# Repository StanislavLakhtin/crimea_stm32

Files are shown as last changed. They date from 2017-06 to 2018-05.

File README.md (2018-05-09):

# crimea_opendac
16 bit usb headphone amplifier on PCM1794A+PGA4311+OPA4134 managed by stm32f103

## Note

It completely doesn't work now.

## CLion Build Env

-DCMAKE_TOOLCHAIN_FILE=libopencm3.cmake

## About

This is complicated "hello world" project for standalone usb sound card and headphone amplifier based on Texas Instruments PCM2707 and STM Cortex-M3 STMF1.

Создаю этот проект для удовольствия. Если исходные коды проекта, схемы или другие материалы проекта будут полезны, буду очень рад.

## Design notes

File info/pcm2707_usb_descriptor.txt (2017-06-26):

as an example

sl@SilverStone:~$ lsusb -D /dev/bus/usb/003/018

Device: ID 08bb:2704 Texas Instruments Audio Codec
Couldn't open device, some information will be missing
Device Descriptor:
  bLength                18
  bDescriptorType         1
  bcdUSB               1.10
  bDeviceClass            0 (Defined at Interface level)
  bDeviceSubClass         0
  bDeviceProtocol         0
  bMaxPacketSize0         8
  idVendor           0x08bb Texas Instruments
  idProduct          0x2704 Audio Codec
  bcdDevice            1.00
  iManufacturer           1
  iProduct                2
  iSerial                 0
  bNumConfigurations      1

  Configuration Descriptor:
    bLength                 9
    bDescriptorType         2
    wTotalLength          190
    bNumInterfaces          3
    bConfigurationValue     1
    iConfiguration          0
    bmAttributes         0x80
      (Bus Powered)
    MaxPower               20mA

    Interface Descriptor:
      bLength                 9
      bDescriptorType         4
      bInterfaceNumber        0
      bAlternateSetting       0
      bNumEndpoints           0
      bInterfaceClass         1 Audio
      bInterfaceSubClass      1 Control Device
      bInterfaceProtocol      0
      iInterface              0

      AudioControl Interface Descriptor:
        bLength                 9
        bDescriptorType        36
        bDescriptorSubtype      1 (HEADER)
        bcdADC               1.00
        wTotalLength           40
        bInCollection           1
        baInterfaceNr( 0)       1

      AudioControl Interface Descriptor:
        bLength                12
        bDescriptorType        36
        bDescriptorSubtype      2 (INPUT_TERMINAL)
        bTerminalID             1
        wTerminalType      0x0101 USB Streaming
        bAssocTerminal          0
        bNrChannels             2
        wChannelConfig     0x0003
          Left Front (L)
          Right Front (R)
        iChannelNames           0
        iTerminal               0

      AudioControl Interface Descriptor:
        bLength                 9
        bDescriptorType        36
        bDescriptorSubtype      3 (OUTPUT_TERMINAL)
        bTerminalID             2
        wTerminalType      0x0301 Speaker
        bAssocTerminal          0
        bSourceID               3
        iTerminal               0

      AudioControl Interface Descriptor:
        bLength                10
        bDescriptorType        36
        bDescriptorSubtype      6 (FEATURE_UNIT)
        bUnitID                 3
        bSourceID               1
        bControlSize            1
        bmaControls( 0)      0x01
          Mute Control
        bmaControls( 1)      0x02
          Volume Control
        bmaControls( 2)      0x02
          Volume Control
        iFeature                0

    Interface Descriptor:
      bLength                 9
      bDescriptorType         4
      bInterfaceNumber        1
      bAlternateSetting       0
      bNumEndpoints           0
      bInterfaceClass         1 Audio
      bInterfaceSubClass      2 Streaming
      bInterfaceProtocol      0
      iInterface              0

    Interface Descriptor:
      bLength                 9
      bDescriptorType         4
      bInterfaceNumber        1
      bAlternateSetting       1
      bNumEndpoints           1
      bInterfaceClass         1 Audio
      bInterfaceSubClass      2 Streaming
      bInterfaceProtocol      0
      iInterface              0

      AudioStreaming Interface Descriptor:
        bLength                 7
        bDescriptorType        36
        bDescriptorSubtype      1 (AS_GENERAL)
        bTerminalLink           1
        bDelay                  0 frames
        wFormatTag              1 PCM

      AudioStreaming Interface Descriptor:
        bLength                17
        bDescriptorType        36
        bDescriptorSubtype      2 (FORMAT_TYPE)
        bFormatType             1 (FORMAT_TYPE_I)
        bNrChannels             2
        bSubframeSize           2
        bBitResolution         16
        bSamFreqType            3 Discrete
        tSamFreq[ 0]        32000
        tSamFreq[ 1]        44100
        tSamFreq[ 2]        48000

      Endpoint Descriptor:
        bLength                 9
        bDescriptorType         5
        bEndpointAddress     0x02  EP 2 OUT
        bmAttributes            9
          Transfer Type            Isochronous
          Synch Type               Adaptive
          Usage Type               Data
        wMaxPacketSize     0x00c0  1x 192 bytes
        bInterval               1
        bRefresh                0
        bSynchAddress           0
        AudioControl Endpoint Descriptor:
          bLength                 7
          bDescriptorType        37
          bDescriptorSubtype      1 (EP_GENERAL)
          bmAttributes         0x00
          bLockDelayUnits         2 Decoded PCM samples
          wLockDelay            512 Decoded PCM samples
    Interface Descriptor:
      bLength                 9
      bDescriptorType         4
      bInterfaceNumber        1
      bAlternateSetting       2
      bNumEndpoints           1
      bInterfaceClass         1 Audio
      bInterfaceSubClass      2 Streaming
      bInterfaceProtocol      0
      iInterface              0
      AudioStreaming Interface Descriptor:
        bLength                 7
        bDescriptorType        36
        bDescriptorSubtype      1 (AS_GENERAL)
        bTerminalLink           1
        bDelay                  0 frames
        wFormatTag              1 PCM
      AudioStreaming Interface Descriptor:
        bLength                17
        bDescriptorType        36
        bDescriptorSubtype      2 (FORMAT_TYPE)
        bFormatType             1 (FORMAT_TYPE_I)
        bNrChannels             1
        bSubframeSize           2
        bBitResolution         16
        bSamFreqType            3 Discrete
        tSamFreq[ 0]        32000
        tSamFreq[ 1]        44100
        tSamFreq[ 2]        48000
      Endpoint Descriptor:
        bLength                 9
        bDescriptorType         5
        bEndpointAddress     0x02  EP 2 OUT
        bmAttributes            9
          Transfer Type            Isochronous
          Synch Type               Adaptive
          Usage Type               Data
        wMaxPacketSize     0x0060  1x 96 bytes
        bInterval               1
        bRefresh                0
        bSynchAddress           0
        AudioControl Endpoint Descriptor:
          bLength                 7
          bDescriptorType        37
          bDescriptorSubtype      1 (EP_GENERAL)
          bmAttributes         0x00
          bLockDelayUnits         2 Decoded PCM samples
          wLockDelay            512 Decoded PCM samples
    Interface Descriptor:
      bLength                 9
      bDescriptorType         4
      bInterfaceNumber        2
      bAlternateSetting       0
      bNumEndpoints           1
      bInterfaceClass         3 Human Interface Device
      bInterfaceSubClass      0 No Subclass
      bInterfaceProtocol      0 None
      iInterface              0
        HID Device Descriptor:
          bLength                 9
          bDescriptorType        33
          bcdHID               1.00
          bCountryCode            0 Not supported
          bNumDescriptors         1
          bDescriptorType        34 Report
          wDescriptorLength      36
         Report Descriptors:
           ** UNAVAILABLE **
      Endpoint Descriptor:
        bLength                 7
        bDescriptorType         5
        bEndpointAddress     0x85  EP 5 IN
        bmAttributes            3
          Transfer Type            Interrupt
          Synch Type               None
          Usage Type               Data
        wMaxPacketSize     0x0001  1x 1 bytes
        bInterval              10

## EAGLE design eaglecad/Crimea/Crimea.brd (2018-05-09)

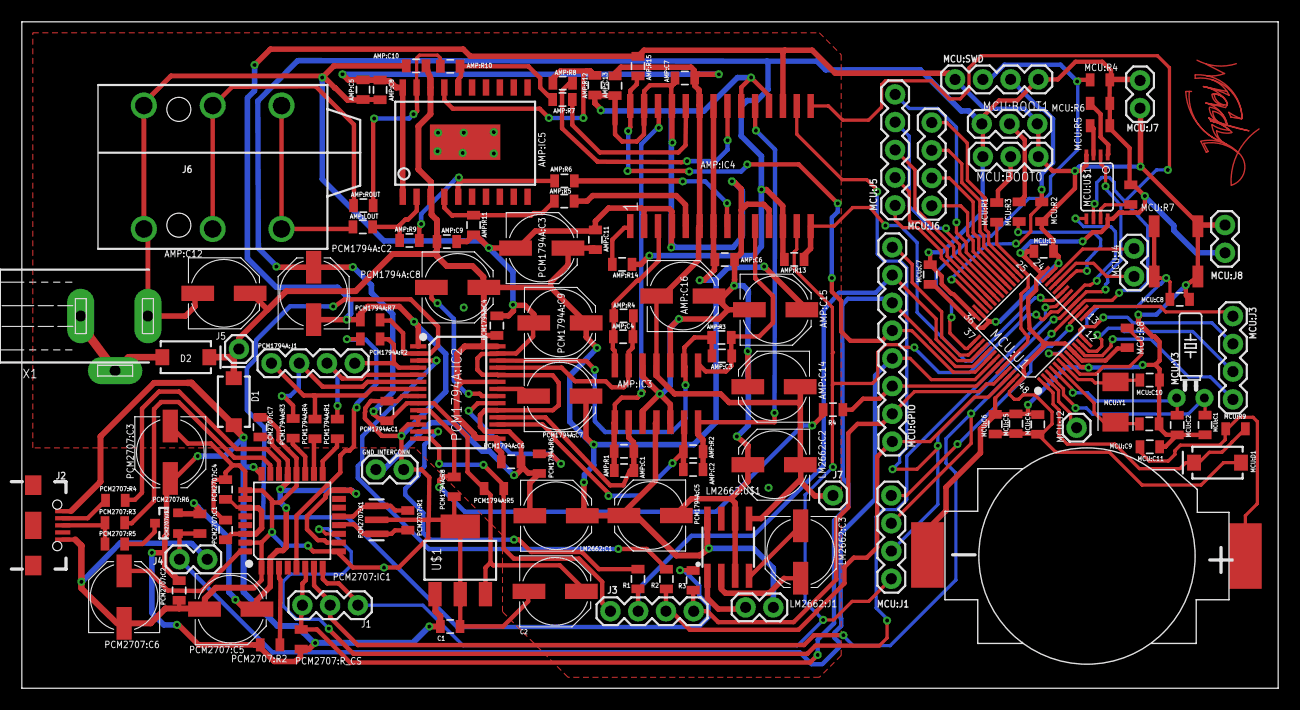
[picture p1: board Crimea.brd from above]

Board: 2 copper layers, 115.0 x 61.0 mm, 135 parts (0 on the bottom side), 104 nets.

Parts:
AMP:C1, AMP:C2, AMP:C3, AMP:C4: 2.7nF; 0805
AMP:C5, AMP:C6, AMP:C7, AMP:C9, AMP:C11, AMP:C13: 0.1uF; 0805
AMP:C8, AMP:C10: 10uF; 0805
AMP:C12, AMP:C14: 10uF; PANASONIC_D
AMP:C15, AMP:C16: 100uF; PANASONIC_D
AMP:IC3: OPA4134D; SO14
AMP:IC4: PGA4311; SOP28
AMP:IC5: TPA6120A2; SOIC20S
AMP:LOUT: 37,8; 0805
AMP:R1, AMP:R2, AMP:R3, AMP:R4, AMP:R5, AMP:R6, AMP:R7, AMP:R8, AMP:R9, AMP:R10, AMP:R11, AMP:R12: 1K; 0805
AMP:R13, AMP:R14, AMP:R15: 100K; 0805
AMP:ROUT: 37,8; 0805
C1: 1.5uF; 0805
C2: 220uF; PANASONIC_D
D1: 0.5A/5V; SMA-DIODE
D2: 1.5A/5V; SMA-DIODE
GND_INTERCONN: GNDCONNECTOR; 1X02
J1: SPI; 1X03
J2: USB_MICRO; USB-AB-MICRO-SMD
J3: SWITCHERS; 1X04
J4: PULLUP; 1X02
J5: V+; 1X01
J6: HEADPHONES; AUDIO_JACK_0.25"_TRS_PTH_RA
J7: 1X01
LM2662:C1: 150nF; PANASONIC_D
LM2662:C2, LM2662:C3: 47uF; PANASONIC_D
LM2662:J1: 20/150Khz; 1X02
LM2662:U$1: LM2662; SOIC-8
MCU:BOOT0, MCU:BOOT1: 1X03
MCU:C1, MCU:C2, MCU:C8, MCU:C9, MCU:C10: 22pF; 0805
MCU:C3, MCU:C4, MCU:C5, MCU:C6, MCU:C7: 1uF; 0805
MCU:C11: 100nF; 0805
MCU:D1: 1A/5V/500mV; SMA-DIODE
MCU:GPIO: GPIO; 1X08
MCU:J1: SPI1; 1X04
MCU:J2: 1X01
MCU:J3: USART2; 1X04
MCU:J4: I2C_2; 1X02
MCU:J5: USART1; 1X05
MCU:J6: SPI2; 1X04
MCU:J7, MCU:J8: POWER; 1X02
MCU:R1, MCU:R2, MCU:R5, MCU:R6, MCU:R7, MCU:R8: 100K; 0805
MCU:R3, MCU:R4: 10K; 0805
MCU:R9: 100; 0805
MCU:SWD: DEBUG; 1X04
MCU:U1: STM32F103CBT6-LQFP48; LQFP48-0.5-7X7MM
MCU:U$1: M95320-D; TSSOP8
MCU:U$2: PUSHBUTTON; PUSHBUTTON_4X4
MCU:U$3: 20MM_BATTERY_3V
MCU:Y1: 16 Mhz; CRYSTAL-TXC-7A
MCU:Y3: 32.768kHz; CRYSTAL-PTH-2X6-CYL-KIT
PCM1794A:C1, PCM1794A:C4, PCM1794A:C6: 0.1uF; 0805
PCM1794A:C2, PCM1794A:C3, PCM1794A:C5, PCM1794A:C9, PCM2707:C5, PCM2707:C6: 10uF; PANASONIC_D
PCM1794A:C7, PCM1794A:C8: 47uF; PANASONIC_D
PCM1794A:IC2: PCM1794A; SSOP28-0.65-10.2X5.2MM
PCM1794A:J1: I2S; 1X04
PCM1794A:R1, PCM1794A:R5: 27; 0805
PCM1794A:R2, PCM1794A:R3, PCM1794A:R4: 10; 0805
PCM1794A:R6: 10K; 0805
PCM1794A:R7, PCM1794A:R8: 100K; 0805
PCM2707:C1, PCM2707:C2, PCM2707:C4, PCM2707:C7: 1uF; 0805
PCM2707:C3: 0.1uF; PANASONIC_D
PCM2707:IC1: PCM2707; TQFP32-0.8-7X7MM
PCM2707:R1: 1M; 0805
PCM2707:R2: 400k; 0805
PCM2707:R3, PCM2707:R4: 22; 0805
PCM2707:R5: 1.5K; 0805
PCM2707:R6: 400K; 0805
PCM2707:R_CS: 100k; 0805
PCM2707:U$2: IRLML2246TRPBF; SOT23-3
PCM2707:X1: 12MHz CSTCE12MOG52-R0; RESONATOR-SMD-3.2X1.3
R1, R2, R3, R4: 20; 0805
U$1: LM3940IMP-3.3/NOPB; SOT223
U$3: CRIMEA_TOP
X1: EXT_+5V; 733980-62

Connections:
!PCM2702_CS!: J1.3, MCU:GPIO.6, MCU:U1.40, PCM2707:IC1.6, PCM2707:R_CS.1
!PGA4311_CS!: AMP:IC4.14, AMP:R13.2, MCU:U1.19
!RST!: J3.1, PCM1794A:IC2.14, PCM1794A:R5.1
!SSPND!: MCU:U1.18, PCM2707:IC1.11
+3.3V: AMP:IC4.12, AMP:R13.1, AMP:R14.1, C2.+, MCU:BOOT0.3, MCU:BOOT1.3, MCU:C3.2, MCU:C4.2, MCU:C5.2, MCU:C6.2, MCU:C7.2, MCU:D1.A, MCU:J7.1, MCU:J8.1, MCU:R4.2, MCU:R5.2, MCU:R6.2, MCU:R7.2, MCU:R8.2, MCU:SWD.1, MCU:U1.9, MCU:U1.24, MCU:U1.36, MCU:U1.48, MCU:U$1.8, PCM1794A:C1.2, PCM1794A:C2.+, PCM1794A:IC2.9, PCM1794A:R5.2, U$1.3
AMP:!MUTE!: AMP:IC4.1, AMP:R14.2
AMP:AMP_A: AMP:C1.1, AMP:IC3.1, AMP:IC4.26, AMP:R1.1
AMP:AMP_B: AMP:C2.1, AMP:IC3.7, AMP:IC4.19, AMP:R2.1
AMP:AMP_C: AMP:C3.1, AMP:IC3.8, AMP:IC4.10, AMP:R3.1
AMP:AMP_D: AMP:C4.1, AMP:IC3.14, AMP:IC4.3, AMP:R4.1
AMP:N$2: AMP:IC5.5, AMP:R6.1, AMP:R9.2
AMP:N$3: AMP:IC5.4, AMP:R5.1, AMP:R11.1
AMP:N$5: AMP:IC5.16, AMP:R7.1, AMP:R10.2
AMP:N$6: AMP:IC5.17, AMP:R8.1, AMP:R12.1
AMP:N$8: AMP:IC5.2, AMP:LOUT.2, AMP:R9.1
AMP:N$9: AMP:IC5.19, AMP:R10.1, AMP:ROUT.2
AMP:VOL_A: AMP:IC4.24, AMP:R7.2
AMP:VOL_B: AMP:IC4.21, AMP:R8.2
AMP:VOL_C: AMP:IC4.8, AMP:R6.2
AMP:VOL_D: AMP:IC4.5, AMP:R5.2
CHSL: PCM1794A:IC2.2, PCM1794A:R7.2, R3.2
DEM: PCM1794A:IC2.3, R2.2
DGND: AMP:IC4.17, AMP:R15.1, C1.2, C2.-, GND_INTERCONN.2, J2.GND1, J4.2, MCU:BOOT0.1, MCU:BOOT1.1, MCU:C1.1, MCU:C2.1, MCU:C3.1, MCU:C4.1, MCU:C5.1, MCU:C6.1, MCU:C7.1, MCU:C8.1, MCU:C9.1, MCU:C10.1, MCU:C11.1, MCU:J7.2, MCU:J8.2, MCU:R3.1, MCU:SWD.4, MCU:U1.8, MCU:U1.23, MCU:U1.35, MCU:U1.47, MCU:U$1.4, MCU:U$2.P$3, MCU:U$2.P$4, MCU:U$3.MINUS, PCM1794A:C1.1, PCM1794A:C2.-, PCM1794A:IC2.1, PCM1794A:IC2.8, PCM1794A:IC2.11, PCM1794A:IC2.12, PCM1794A:R7.1, PCM1794A:R8.1, PCM2707:C1.2, PCM2707:C2.1, PCM2707:C3.-, PCM2707:C4.1, PCM2707:C5.-, PCM2707:C6.-, PCM2707:C7.1, PCM2707:IC1.1, PCM2707:IC1.9, PCM2707:IC1.20, PCM2707:IC1.25, PCM2707:IC1.26, PCM2707:IC1.31, PCM2707:X1.2, U$1.2, U$1.4
EXT+5V: D2.A, X1.2, X1.3
GND: AMP:C5.2, AMP:C6.2, AMP:C7.2, AMP:C8.2, AMP:C9.2, AMP:C10.2, AMP:C11.1, AMP:C12.-, AMP:C13.2, AMP:C14.+, AMP:C15.-, AMP:C16.+, AMP:IC3.3, AMP:IC3.5, AMP:IC3.10, AMP:IC3.12, AMP:IC4.2, AMP:IC4.4, AMP:IC4.9, AMP:IC4.11, AMP:IC4.18, AMP:IC4.20, AMP:IC4.25, AMP:IC4.27, AMP:R11.2, AMP:R12.2, GND_INTERCONN.1, J6.SLEEVE, J6.SLEEVE-NORM, LM2662:C1.-, LM2662:C2.+, LM2662:U$1.3, LM2662:U$1.6, PCM1794A:C3.-, PCM1794A:C4.2, PCM1794A:C5.-, PCM1794A:C6.1, PCM1794A:C9.-, PCM1794A:IC2.16, PCM1794A:IC2.19, PCM1794A:IC2.24, PCM1794A:IC2.27, PCM1794A:R6.2, X1.1
LM2662:FC: LM2662:J1.1, LM2662:U$1.1
LM2662:N$1: LM2662:C3.+, LM2662:U$1.2
LM2662:N$2: LM2662:C3.-, LM2662:U$1.4
MCU:!EEPROM_CS!: MCU:R6.1, MCU:U$1.1
MCU:!EEPROM_HOLD!: MCU:R7.1, MCU:U$1.7
MCU:!RST!: MCU:C8.2, MCU:R8.1, MCU:U1.7, MCU:U$2.P$1, MCU:U$2.P$2
MCU:!W!: MCU:R5.1, MCU:U$1.3
MCU:BOOT0: MCU:R1.2, MCU:U1.44
MCU:I2C2_SCL: MCU:J4.2, MCU:U1.21
MCU:I2C2_SDA: MCU:J4.1, MCU:U1.22
MCU:N$1: MCU:D1.C, MCU:R9.2, MCU:U1.1
MCU:N$3: MCU:C11.2, MCU:R9.1, MCU:U$3.PLUS
MCU:N$7: MCU:BOOT0.2, MCU:R1.1
MCU:N$10: MCU:BOOT1.2, MCU:R2.1
MCU:OSC32_IN: MCU:C1.2, MCU:U1.3, MCU:Y3.2
MCU:OSC32_OUT: MCU:C2.2, MCU:U1.4, MCU:Y3.1
MCU:OSC_IN: MCU:C9.2, MCU:U1.5, MCU:Y1.P$2
MCU:OSC_OUT: MCU:C10.2, MCU:U1.6, MCU:Y1.P$1
MCU:PA8: MCU:J5.5, MCU:U1.29
MCU:PA9: MCU:J5.4, MCU:U1.30
MCU:PA10: MCU:J5.3, MCU:U1.31
MCU:PA11: MCU:J5.2, MCU:U1.32
MCU:PA12: MCU:J5.1, MCU:U1.33
MCU:PA15: MCU:GPIO.8, MCU:U1.38
MCU:PB2: MCU:R2.2, MCU:U1.20
MCU:PB15: MCU:J6.1, MCU:U1.28
MCU:PC13: MCU:J2.1, MCU:U1.2
MCU:SPI1_NSS: MCU:J1.4, MCU:U1.14
MCU:SPI2_MISO: MCU:J6.2, MCU:U1.27
MCU:SPI2_NSS: MCU:J6.4, MCU:U1.25
MCU:SPI2_SCK: MCU:J6.3, MCU:U1.26
MCU:SWDCLK: MCU:R4.1, MCU:SWD.3, MCU:U1.37
MCU:SWDIO: MCU:R3.2, MCU:SWD.2, MCU:U1.34
MCU:USART2_CTS: MCU:J3.4, MCU:U1.10
MCU:USART2_RTS: MCU:J3.3, MCU:U1.11
MCU:USART2_RX: MCU:J3.1, MCU:U1.13
MCU:USART2_TX: MCU:J3.2, MCU:U1.12
MUTE: MCU:GPIO.3, MCU:U1.43, R4.1
unnamed: J2.D-1, PCM2707:R4.2
unnamed: J2.D+1, PCM2707:R3.2, PCM2707:R5.2
unnamed: AMP:C3.2, AMP:IC3.9, AMP:R3.2, PCM1794A:IC2.26
unnamed: AMP:LOUT.1, J6.TIP, J6.TIP-NORM
unnamed: PCM1794A:R4.1, PCM2707:IC1.18
unnamed: PCM1794A:R2.1, PCM2707:IC1.5
unnamed: PCM1794A:R3.1, PCM2707:IC1.19
unnamed: PCM1794A:R1.1, PCM2707:IC1.17
unnamed: AMP:ROUT.1, J6.RING, J6.RING-NORM
unnamed: AMP:C4.2, AMP:IC3.13, AMP:R4.2, PCM1794A:IC2.25
unnamed: PCM1794A:IC2.10, PCM1794A:R8.2, R4.2
unnamed: AMP:C1.2, AMP:IC3.2, AMP:R1.2, PCM1794A:IC2.18
unnamed: AMP:C2.2, AMP:IC3.6, AMP:R2.2, PCM1794A:IC2.17
PB3: J3.2, MCU:GPIO.7, MCU:U1.39, R1.1
PB8: J3.4, MCU:GPIO.2, MCU:U1.45, R3.1
PB9: J3.3, MCU:GPIO.1, MCU:U1.46, R2.1
PCM1794A:BCK_INT: PCM1794A:IC2.6, PCM1794A:J1.2, PCM1794A:R3.2
PCM1794A:DATA_INT: PCM1794A:IC2.5, PCM1794A:J1.3, PCM1794A:R1.2
PCM1794A:LRCK_INT: PCM1794A:IC2.4, PCM1794A:J1.4, PCM1794A:R2.2
PCM1794A:N$4: PCM1794A:IC2.20, PCM1794A:R6.1
PCM1794A:N$9: PCM1794A:C7.-, PCM1794A:IC2.22
PCM1794A:N$10: PCM1794A:C8.-, PCM1794A:IC2.21
PCM1794A:SCK_INT: PCM1794A:IC2.7, PCM1794A:J1.1, PCM1794A:R4.2
PCM2707:INTRNL_D+: PCM2707:IC1.23, PCM2707:R3.1
PCM2707:INTRNL_D-: PCM2707:IC1.22, PCM2707:R4.1
PCM2707:INTRNL_HOST: PCM2707:IC1.3, PCM2707:R2.2
PCM2707:INT_3.3V: PCM2707:C5.+, PCM2707:C7.2, PCM2707:IC1.2, PCM2707:IC1.10, PCM2707:IC1.16, PCM2707:IC1.21, PCM2707:R6.1, PCM2707:U$2.2
PCM2707:N$2: PCM2707:C1.1, PCM2707:C4.2, PCM2707:IC1.27, PCM2707:IC1.30
PCM2707:N$9: PCM2707:R5.1, PCM2707:U$2.3
PCM2707:RESONATOR_XTI: PCM2707:IC1.12, PCM2707:R1.1, PCM2707:X1.1
PCM2707:RESONATOR_XTO: PCM2707:IC1.13, PCM2707:R1.2, PCM2707:X1.3
PCM2707:VCOM: PCM2707:C6.+, PCM2707:IC1.32
PULLUP_D+: J4.1, MCU:GPIO.4, MCU:U1.42, PCM2707:R6.2, PCM2707:U$2.1
SPI_MISO: AMP:IC4.16, MCU:J1.2, MCU:U1.16, MCU:U$1.2
SPI_MOSI: AMP:IC4.13, J1.1, MCU:J1.1, MCU:U1.17, MCU:U$1.5, PCM2707:IC1.8
SPI_SCK: AMP:IC4.15, J1.2, MCU:J1.3, MCU:U1.15, MCU:U$1.6, PCM2707:IC1.7
USB+5V: C1.1, D1.A, J2.VBUS1, PCM2707:C2.2, PCM2707:C3.+, PCM2707:IC1.24, PCM2707:R2.1, PCM2707:R_CS.2, U$1.1
V+: AMP:C6.1, AMP:C9.1, AMP:C10.1, AMP:C11.2, AMP:C12.+, AMP:C15.+, AMP:IC3.4, AMP:IC4.7, AMP:IC4.22, AMP:IC5.3, AMP:IC5.18, D1.C, D2.C, J5.1, LM2662:C1.+, LM2662:J1.2, LM2662:U$1.8, PCM1794A:C3.+, PCM1794A:C4.1, PCM1794A:C5.+, PCM1794A:C6.2, PCM1794A:C7.+, PCM1794A:C8.+, PCM1794A:C9.+, PCM1794A:IC2.15, PCM1794A:IC2.23, PCM1794A:IC2.28
V-: AMP:C5.1, AMP:C7.1, AMP:C8.1, AMP:C13.1, AMP:C14.-, AMP:C16.-, AMP:IC3.11, AMP:IC4.6, AMP:IC4.23, AMP:IC5.1, AMP:IC5.20, J7.1, LM2662:C2.-, LM2662:U$1.5
ZCEN: AMP:IC4.28, AMP:R15.2, MCU:GPIO.5, MCU:U1.41
ZERO: PCM1794A:IC2.13, R1.2

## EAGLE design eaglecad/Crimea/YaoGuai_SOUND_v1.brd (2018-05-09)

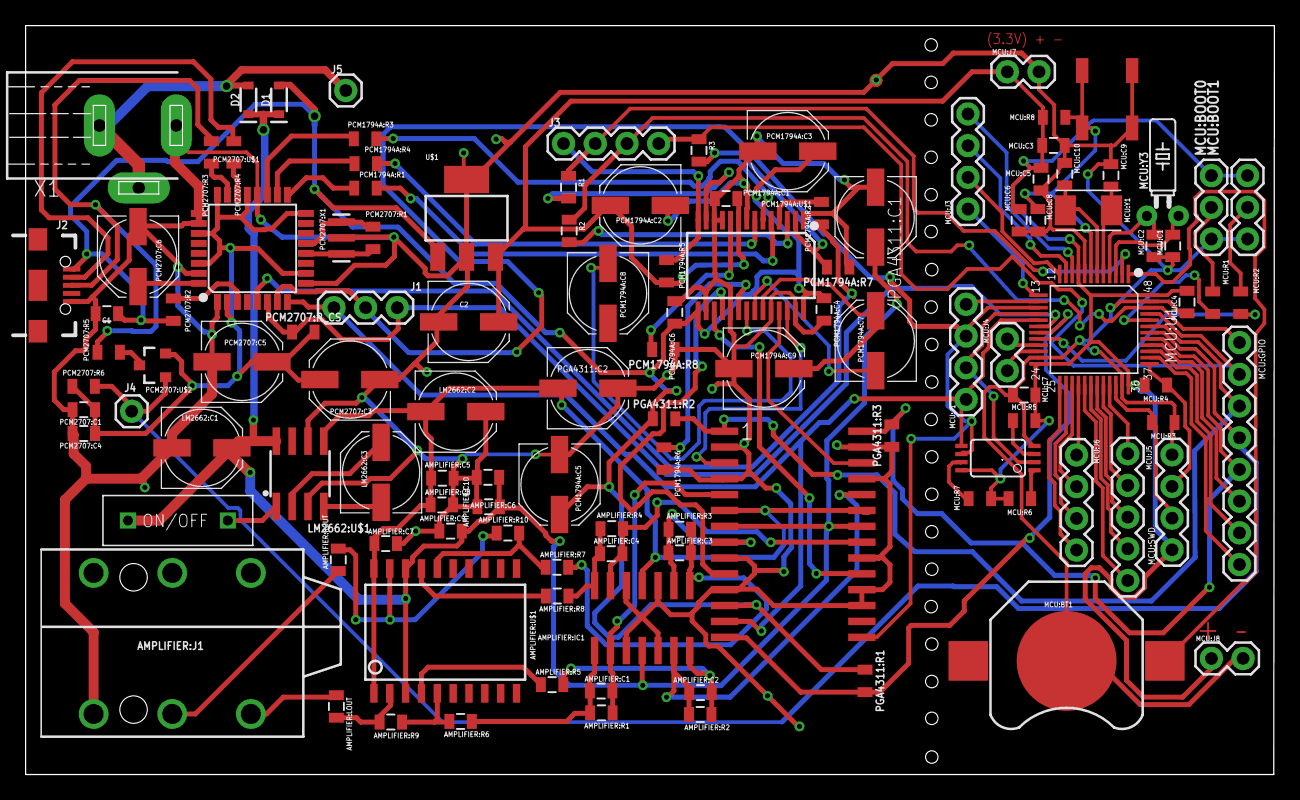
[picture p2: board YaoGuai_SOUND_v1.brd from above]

Board: 2 copper layers, 100.0 x 60.0 mm, 118 parts (0 on the bottom side), 101 nets.

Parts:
AMPLIFIER:C1, AMPLIFIER:C2, AMPLIFIER:C3, AMPLIFIER:C4: 2.7nF; 0805
AMPLIFIER:C5, AMPLIFIER:C6, AMPLIFIER:C7, AMPLIFIER:C9: 0.1uF; 0805
AMPLIFIER:C8, AMPLIFIER:C10: 10uF; 0805
AMPLIFIER:IC1: OPA4134D; SO14
AMPLIFIER:J1: AUDIO_JACK_TRS_0.25"_PTH_RA; AUDIO_JACK_0.25"_TRS_PTH_RA
AMPLIFIER:LOUT: 50; 0805
AMPLIFIER:R1, AMPLIFIER:R2, AMPLIFIER:R3, AMPLIFIER:R4, AMPLIFIER:R5, AMPLIFIER:R6, AMPLIFIER:R7, AMPLIFIER:R8, AMPLIFIER:R9, AMPLIFIER:R10: 1K; 0805
AMPLIFIER:ROUT: 50; 0805
AMPLIFIER:U$1: TPA6120A2; SOIC20S
C1: 1.5uF; 0805
C2: 220uF; PANASONIC_D
D1, D2: 0.5A/40V/420mV; SOD-323
J1: 1X03
J2: USB-AB-MICRO-SMD
J3: 1X04
J4, J5: 1X01
LM2662:C1: 150nF; PANASONIC_D
LM2662:C2, LM2662:C3: 47uF; PANASONIC_D
LM2662:U$1: LM2662; SOIC-8
LM2662:U$2: RED_SWITCH_ON; RED_SWITCH
MCU:BOOT0, MCU:BOOT1: 1X03
MCU:BT1: BATTCON_12MM
MCU:C1, MCU:C2, MCU:C8, MCU:C9, MCU:C10: 22pF; 0805
MCU:C3, MCU:C4, MCU:C5, MCU:C6, MCU:C7: 1uF; 0805
MCU:GPIO: 1X08
MCU:J1: SPI1; 1X04
MCU:J3: USART2; 1X04
MCU:J4: I2C_2; 1X02
MCU:J5: USART1; 1X05
MCU:J6: SPI2; 1X04
MCU:J7, MCU:J8: POWER; 1X02
MCU:R1, MCU:R2, MCU:R5, MCU:R6, MCU:R7, MCU:R8: 100K; 0805
MCU:R3, MCU:R4: 10K; 0805
MCU:SWD: 1X04
MCU:U1: STM32F103CBT6-LQFP48; LQFP48-0.5-7X7MM
MCU:U$1: M95320-D; TSSOP8
MCU:U$2: PUSHBUTTON; PUSHBUTTON_4X4
MCU:Y1: CRYSTAL-TXC-7A
MCU:Y3: 32.768kHz; CRYSTAL-PTH-2X6-CYL-KIT
PCM1794A:C1, PCM1794A:C4, PCM1794A:C6: 0.1uF; 0805
PCM1794A:C2, PCM1794A:C3, PCM1794A:C5, PCM1794A:C9, PCM2707:C5, PCM2707:C6: 10uF; PANASONIC_D
PCM1794A:C7, PCM1794A:C8: 47uF; PANASONIC_D
PCM1794A:R1, PCM1794A:R2, PCM1794A:R3, PCM1794A:R4, PCM1794A:R5: 27; 0805
PCM1794A:R6: 10K; 0805
PCM1794A:R7, PCM1794A:R8: 100K; 0805
PCM1794A:U$1: PCM1794A; SSOP28-0.65-10.2X5.2MM
PCM2707:C1, PCM2707:C4: 1uF; 0805
PCM2707:C3: 0.1uF; PANASONIC_D
PCM2707:R1, PCM2707:R2, PCM2707:R6: 1M; 0805
PCM2707:R3, PCM2707:R4: 22; 0805
PCM2707:R5: 1.5K; 0805
PCM2707:R_CS: 100k; 0805
PCM2707:U$1: PCM2707; TQFP32-0.8-7X7MM
PCM2707:U$2: IRLML2246TRPBF; SOT23-3
PCM2707:X1: 12MHz; RESONATOR-SMD-3.2X1.3
PGA4311:C1, PGA4311:C2: PANASONIC_D
PGA4311:R1: 0805
PGA4311:R2, PGA4311:R3: 100K; 0805
PGA4311:U$1: PGA4311; SOP28
R1, R2, R3: 20; 0805
U$1: LM3940IMP-3.3/NOPB; SOT223
X1: 733980-62

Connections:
3.3V: C2.+, MCU:BOOT0.3, MCU:BOOT1.3, MCU:C3.2, MCU:C4.2, MCU:C5.2, MCU:C6.2, MCU:C7.2, MCU:J7.1, MCU:J8.1, MCU:R4.2, MCU:R5.2, MCU:R6.2, MCU:R7.2, MCU:R8.2, MCU:SWD.1, MCU:U1.9, MCU:U1.24, MCU:U1.36, MCU:U1.48, MCU:U$1.8, PCM1794A:C1.2, PCM1794A:C2.+, PCM1794A:R5.2, PCM1794A:U$1.9, U$1.3
!MUTE!: MCU:GPIO.3, MCU:U1.43, PGA4311:R2.2, PGA4311:U$1.1
!PCM2702_CS!: J1.3, MCU:U1.18, PCM2707:R_CS.1, PCM2707:U$1.6
!PGA4311_CS!: MCU:U1.19, PGA4311:R1.2, PGA4311:U$1.14
AMPLIFIER:N$1: AMPLIFIER:C1.1, AMPLIFIER:IC1.1, AMPLIFIER:R1.1, AMPLIFIER:R6.2
AMPLIFIER:N$2: AMPLIFIER:R6.1, AMPLIFIER:R9.2, AMPLIFIER:U$1.5
AMPLIFIER:N$3: AMPLIFIER:R5.1, AMPLIFIER:U$1.4
AMPLIFIER:N$4: AMPLIFIER:C2.1, AMPLIFIER:IC1.7, AMPLIFIER:R2.1, AMPLIFIER:R5.2
AMPLIFIER:N$5: AMPLIFIER:R7.1, AMPLIFIER:R10.2, AMPLIFIER:U$1.16
AMPLIFIER:N$6: AMPLIFIER:R8.1, AMPLIFIER:U$1.17
AMPLIFIER:N$7: AMPLIFIER:C3.1, AMPLIFIER:IC1.8, AMPLIFIER:R3.1, AMPLIFIER:R7.2
AMPLIFIER:N$8: AMPLIFIER:LOUT.2, AMPLIFIER:R9.1, AMPLIFIER:U$1.2
AMPLIFIER:N$9: AMPLIFIER:R10.1, AMPLIFIER:ROUT.2, AMPLIFIER:U$1.19
AMPLIFIER:N$10: AMPLIFIER:C4.1, AMPLIFIER:IC1.14, AMPLIFIER:R4.1, AMPLIFIER:R8.2
AMPLIFIER:N$11: AMPLIFIER:J1.RING, AMPLIFIER:ROUT.1
AMPLIFIER:N$12: AMPLIFIER:J1.TIP, AMPLIFIER:LOUT.1
CHSL: PCM1794A:R7.2, PCM1794A:U$1.2, R3.2
DEM: PCM1794A:U$1.3, R2.2
EXT+5V: D2.A, J5.1, X1.2, X1.3
GND: AMPLIFIER:C5.2, AMPLIFIER:C6.2, AMPLIFIER:C7.2, AMPLIFIER:C8.2, AMPLIFIER:C9.2, AMPLIFIER:C10.2, AMPLIFIER:IC1.3, AMPLIFIER:IC1.5, AMPLIFIER:IC1.10, AMPLIFIER:IC1.12, AMPLIFIER:J1.SLEEVE, C1.2, C2.-, J2.GND1, LM2662:C1.-, LM2662:C2.+, LM2662:U$1.3, LM2662:U$1.6, MCU:BOOT0.1, MCU:BOOT1.1, MCU:BT1.GND, MCU:C1.1, MCU:C2.1, MCU:C3.1, MCU:C4.1, MCU:C5.1, MCU:C6.1, MCU:C7.1, MCU:C8.1, MCU:C9.1, MCU:C10.1, MCU:J7.2, MCU:J8.2, MCU:R3.1, MCU:SWD.4, MCU:U1.8, MCU:U1.23, MCU:U1.35, MCU:U1.47, MCU:U$1.4, MCU:U$2.P$3, MCU:U$2.P$4, PCM1794A:C1.1, PCM1794A:C2.-, PCM1794A:C3.-, PCM1794A:C4.2, PCM1794A:C5.-, PCM1794A:C6.1, PCM1794A:C9.-, PCM1794A:R6.2, PCM1794A:R7.1, PCM1794A:R8.1, PCM1794A:U$1.1, PCM1794A:U$1.8, PCM1794A:U$1.11, PCM1794A:U$1.12, PCM1794A:U$1.16, PCM1794A:U$1.19, PCM1794A:U$1.24, PCM1794A:U$1.27, PCM2707:C1.2, PCM2707:C3.-, PCM2707:C4.1, PCM2707:C5.-, PCM2707:C6.-, PCM2707:U$1.1, PCM2707:U$1.9, PCM2707:U$1.20, PCM2707:U$1.25, PCM2707:U$1.26, PCM2707:U$1.31, PCM2707:X1.2, PGA4311:C1.-, PGA4311:C2.+, PGA4311:R3.1, PGA4311:U$1.2, PGA4311:U$1.4, PGA4311:U$1.9, PGA4311:U$1.11, PGA4311:U$1.17, PGA4311:U$1.18, PGA4311:U$1.20, PGA4311:U$1.25, PGA4311:U$1.27, U$1.2, U$1.4, X1.1
LM2662:FC: LM2662:U$1.1, LM2662:U$2.P$1
LM2662:N$1: LM2662:C3.+, LM2662:U$1.2
LM2662:N$2: LM2662:C3.-, LM2662:U$1.4
MCU:!EEPROM_CS!: MCU:R6.1, MCU:U$1.1
MCU:!EEPROM_HOLD!: MCU:R7.1, MCU:U$1.7
MCU:!RST!: MCU:C8.2, MCU:R8.1, MCU:U1.7, MCU:U$2.P$1, MCU:U$2.P$2
MCU:!W!: MCU:R5.1, MCU:U$1.3
MCU:I2C2_SCL: MCU:J4.2, MCU:U1.21
MCU:I2C2_SDA: MCU:J4.1, MCU:U1.22
MCU:N$1: MCU:BT1.PWR@1, MCU:U1.1
MCU:N$2: MCU:C10.2, MCU:U1.6, MCU:Y1.P$1
MCU:N$3: MCU:C9.2, MCU:U1.5, MCU:Y1.P$2
MCU:N$4: MCU:C2.2, MCU:U1.4, MCU:Y3.1
MCU:N$5: MCU:C1.2, MCU:U1.3, MCU:Y3.2
MCU:N$6: MCU:J5.3, MCU:U1.31
MCU:N$7: MCU:BOOT0.2, MCU:R1.1
MCU:N$8: MCU:R1.2, MCU:U1.44
MCU:N$9: MCU:J5.2, MCU:U1.32
MCU:N$10: MCU:BOOT1.2, MCU:R2.1
MCU:N$11: MCU:R2.2, MCU:U1.20
MCU:N$12: MCU:J5.1, MCU:U1.33
MCU:N$14: MCU:J5.4, MCU:U1.30
MCU:N$15: MCU:J5.5, MCU:U1.29
MCU:PA15: MCU:GPIO.8, MCU:U1.38
MCU:PB3: MCU:GPIO.7, MCU:U1.39
MCU:PB4: MCU:GPIO.6, MCU:U1.40
MCU:SPI1_MISO: MCU:J1.2, MCU:U1.16, MCU:U$1.2
MCU:SPI1_NSS: MCU:J1.4, MCU:U1.14
MCU:SPI2_MISO: MCU:J6.2, MCU:U1.27
MCU:SPI2_MOSI: MCU:J6.1, MCU:U1.28
MCU:SPI2_NSS: MCU:J6.4, MCU:U1.25
MCU:SPI2_SCK: MCU:J6.3, MCU:U1.26
MCU:SWDCLK: MCU:R4.1, MCU:SWD.3, MCU:U1.37
MCU:SWDIO: MCU:R3.2, MCU:SWD.2, MCU:U1.34
MCU:USART2_CTS: MCU:J3.4, MCU:U1.10
MCU:USART2_RTS: MCU:J3.3, MCU:U1.11
MCU:USART2_RX: MCU:J3.1, MCU:U1.13
MCU:USART2_TX: MCU:J3.2, MCU:U1.12
unnamed: J2.D-1, PCM2707:R4.2
unnamed: J2.D+1, PCM2707:R3.2, PCM2707:R5.2
unnamed: PCM1794A:U$1.26, PGA4311:U$1.3
unnamed: PCM1794A:U$1.25, PGA4311:U$1.26
unnamed: PCM1794A:R4.1, PCM2707:U$1.18
unnamed: PCM1794A:R2.1, PCM2707:U$1.5
unnamed: PCM1794A:R3.1, PCM2707:U$1.19
unnamed: PCM1794A:R1.1, PCM2707:U$1.17
unnamed: PCM1794A:U$1.18, PGA4311:U$1.10
unnamed: PCM1794A:U$1.17, PGA4311:U$1.19
unnamed: J3.2, MCU:U1.2, R1.1
unnamed: J3.3, MCU:GPIO.1, MCU:U1.46, R2.1
unnamed: J3.4, MCU:GPIO.2, MCU:U1.45, R3.1
unnamed: J3.1, PCM1794A:R5.1, PCM1794A:U$1.14
unnamed: AMPLIFIER:C3.2, AMPLIFIER:IC1.9, AMPLIFIER:R3.2, PGA4311:U$1.8
unnamed: AMPLIFIER:C4.2, AMPLIFIER:IC1.13, AMPLIFIER:R4.2, PGA4311:U$1.21
unnamed: AMPLIFIER:C2.2, AMPLIFIER:IC1.6, AMPLIFIER:R2.2, PGA4311:U$1.24
unnamed: AMPLIFIER:C1.2, AMPLIFIER:IC1.2, AMPLIFIER:R1.2, PGA4311:U$1.5
PCM1794A:MUTE: PCM1794A:R8.2, PCM1794A:U$1.10
PCM1794A:N$1: PCM1794A:R4.2, PCM1794A:U$1.7
PCM1794A:N$2: PCM1794A:R3.2, PCM1794A:U$1.6
PCM1794A:N$3: PCM1794A:R1.2, PCM1794A:U$1.5
PCM1794A:N$4: PCM1794A:R6.1, PCM1794A:U$1.20
PCM1794A:N$5: PCM1794A:R2.2, PCM1794A:U$1.4
PCM1794A:N$9: PCM1794A:C7.-, PCM1794A:U$1.22
PCM1794A:N$10: PCM1794A:C8.-, PCM1794A:U$1.21
PCM1794A:V+: PCM1794A:C7.+, PCM1794A:C8.+, PCM1794A:C9.+, PCM1794A:U$1.23
PCM2707:INTRNL_D+: PCM2707:R3.1, PCM2707:U$1.23
PCM2707:INTRNL_D-: PCM2707:R4.1, PCM2707:U$1.22
PCM2707:INTRNL_HOST: PCM2707:R2.2, PCM2707:U$1.3
PCM2707:N$9: PCM2707:R5.1, PCM2707:U$2.3
PCM2707:RESONATOR_XTI: PCM2707:R1.1, PCM2707:U$1.12, PCM2707:X1.1
PCM2707:RESONATOR_XTO: PCM2707:R1.2, PCM2707:U$1.13, PCM2707:X1.3
PCM2707:USB+5V: PCM2707:C1.1, PCM2707:C3.+, PCM2707:C4.2, PCM2707:C5.+, PCM2707:R6.1, PCM2707:R_CS.2, PCM2707:U$1.2, PCM2707:U$1.10, PCM2707:U$1.16, PCM2707:U$1.21, PCM2707:U$1.24, PCM2707:U$1.27, PCM2707:U$1.30, PCM2707:U$2.2
PCM2707:VCOM: PCM2707:C6.+, PCM2707:U$1.32
PULLUP_D+: J4.1, MCU:GPIO.4, MCU:U1.42, PCM2707:R6.2, PCM2707:U$2.1
SPI_MOSI: J1.1, MCU:J1.1, MCU:U1.17, MCU:U$1.5, PCM2707:U$1.8, PGA4311:U$1.13
SPI_SCK: J1.2, MCU:J1.3, MCU:U1.15, MCU:U$1.6, PCM2707:U$1.7, PGA4311:U$1.15
USB+5V: C1.1, D1.A, J2.VBUS1, PCM1794A:C3.+, PCM1794A:C4.1, PCM1794A:C5.+, PCM1794A:C6.2, PCM1794A:U$1.15, PCM1794A:U$1.28, PCM2707:R2.1, PGA4311:R1.1, PGA4311:R2.1, PGA4311:U$1.12, U$1.1
V+: AMPLIFIER:C6.1, AMPLIFIER:C9.1, AMPLIFIER:C10.1, AMPLIFIER:IC1.4, AMPLIFIER:U$1.3, AMPLIFIER:U$1.18, D1.C, D2.C, LM2662:C1.+, LM2662:U$1.8, LM2662:U$2.P$2, PGA4311:C1.+, PGA4311:U$1.7, PGA4311:U$1.22
V-: AMPLIFIER:C5.1, AMPLIFIER:C7.1, AMPLIFIER:C8.1, AMPLIFIER:IC1.11, AMPLIFIER:U$1.1, AMPLIFIER:U$1.20, LM2662:C2.-, LM2662:U$1.5, PGA4311:C2.-, PGA4311:U$1.6, PGA4311:U$1.23
ZCEN: MCU:GPIO.5, MCU:U1.41, PGA4311:R3.2, PGA4311:U$1.28
ZERO: PCM1794A:U$1.13, R1.2

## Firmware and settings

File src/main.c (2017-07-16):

//
// Created by sl on 18.02.17.
//

#include <libopencm3/cm3/nvic.h>
#include <libopencm3/stm32/exti.h>
#include <libopencm3/stm32/gpio.h>
#include <libopencm3/usb/audio.h>
#include <libopencm3/usb/usbd.h>

#include <atom.h>

#include <board_setup.h>

#include <ssd1306_i2c.h>
#include <wchar.h>
#include <crimea_usb.h>

uint8_t volumeControl = 5;
static uint8_t usbd_control_buffer[512];
//static char usb_serial_number[25];

#define STACK_SIZE      1024
#define THREAD_PRIO     42

static ATOM_TCB main_tcb;

static uint8_t thread_stacks[2][STACK_SIZE];

static void main_thread_func(uint32_t data);

usbd_device *usbDev;

void usb_wakeup_isr(void) {
  atomIntEnter();
  usbd_poll(usbDev);
  atomIntExit(0);
}

void usb_lp_can_rx0_isr(void) {
  atomIntEnter();
  usbd_poll(usbDev);
  atomIntExit(0);
}

int main(void) {

  int8_t osInitStatus;

  board_setup();
  encoder_setup(&volumeControl);

  /* Print message */
  //ssd1306_drawWCharStr(0, 0, white, wrapDisplay, L"Крым v2.");
  //ssd1306_refresh();
  usbDev = usbd_init(&stm32f107_usb_driver, &dev, &conf, usb_strings, 3, usbd_control_buffer,
                     sizeof(usbd_control_buffer));
  usbd_register_set_config_callback(usbDev, usb_set_config_handler);
  nvic_enable_irq(NVIC_USB_LP_CAN_RX0_IRQ);
  nvic_enable_irq(NVIC_USB_WAKEUP_IRQ);
  /* USB pull up*/
  usb_pullup();
  /**
 * Initialise OS and set up idle thread
 */
  osInitStatus = atomOSInit(&thread_stacks[0][0], STACK_SIZE, FALSE);

  if (osInitStatus == ATOM_OK) {
    /* Set up main thread */
    osInitStatus = atomThreadCreate(&main_tcb, THREAD_PRIO, main_thread_func, 0,
                              &thread_stacks[1][0], STACK_SIZE, TRUE);

    if (osInitStatus == ATOM_OK) {
      atomOSStart();
    }
  }

  while (1);

  /* We will never get here */
  return 0xff;
}

static void main_thread_func(uint32_t data __maybe_unused) {
  uint8_t vC = volumeControl;
  wchar_t buffer[40];

  /* Loop forever and blink the LED */
  while (1) {
    usbd_poll(usbDev);
    if (vC != volumeControl) {
      //ssd1306_clear();
      vC = volumeControl;
      swprintf(buffer, 40, L"%d", vC);
      //ssd1306_drawWCharStr(0, 8, white, nowrap, L"Volume:");
      //ssd1306_drawWCharStr(0, 16, white, nowrap, buffer);
      //ssd1306_refresh();
    }
    atomTimerDelay(SYSTEM_TICKS_PER_SEC);
  }
}

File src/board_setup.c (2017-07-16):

/*
 * Copyright (c) 2015, Tido Klaassen. All rights reserved.
 *
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
 * 1. Redistributions of source code must retain the above copyright
 *    notice, this list of conditions and the following disclaimer.
 * 2. Redistributions in binary form must reproduce the above copyright
 *    notice, this list of conditions and the following disclaimer in the
 *    documentation and/or other materials provided with the distribution.
 * 3. No personal names or organizations' names associated with the
 *    Atomthreads project may be used to endorse or promote products
 *    derived from this software without specific prior written permission.
 *
 * THIS SOFTWARE IS PROVIDED BY THE ATOMTHREADS PROJECT AND CONTRIBUTORS
 * "AS IS" AND ANY EXPRESS OR IMPLIED WARRANTIES, INCLUDING, BUT NOT LIMITED
 * TO, THE IMPLIED WARRANTIES OF MERCHANTABILITY AND FITNESS FOR A PARTICULAR
 * PURPOSE ARE DISCLAIMED. IN NO EVENT SHALL THE PROJECT OR CONTRIBUTORS BE
 * LIABLE FOR ANY DIRECT, INDIRECT, INCIDENTAL, SPECIAL, EXEMPLARY, OR
 * CONSEQUENTIAL DAMAGES (INCLUDING, BUT NOT LIMITED TO, PROCUREMENT OF
 * SUBSTITUTE GOODS OR SERVICES; LOSS OF USE, DATA, OR PROFITS; OR BUSINESS
 * INTERRUPTION) HOWEVER CAUSED AND ON ANY THEORY OF LIABILITY, WHETHER IN
 * CONTRACT, STRICT LIABILITY, OR TORT (INCLUDING NEGLIGENCE OR OTHERWISE)
 * ARISING IN ANY WAY OUT OF THE USE OF THIS SOFTWARE, EVEN IF ADVISED OF THE
 * POSSIBILITY OF SUCH DAMAGE.
 */

#include <board_setup.h>

#include <stdbool.h>

#include <libopencm3/stm32/rcc.h>
#include <libopencm3/stm32/gpio.h>
#include <libopencm3/cm3/systick.h>
#include <libopencm3/cm3/cortex.h>
#include <libopencm3/cm3/nvic.h>
#include <libopencm3/stm32/spi.h>
#include <atomport.h>
#include <libopencm3/stm32/i2c.h>
#include <ssd1306_i2c.h>

void clock_setup(void) {
  rcc_clock_setup_in_hse_12mhz_out_72mhz();

  rcc_periph_clock_enable(RCC_GPIOA);
  rcc_periph_clock_enable(RCC_GPIOB);
  rcc_periph_clock_enable(RCC_GPIOE);

  /* set clock for I2C */
  rcc_periph_clock_enable(RCC_I2C2);

  /* Enable SPI1 Periph and gpio clocks */
  rcc_periph_clock_enable(RCC_SPI1);

  rcc_periph_clock_enable(RCC_OTGFS);

  rcc_periph_clock_enable(RCC_AFIO);
  AFIO_MAPR |= AFIO_MAPR_SWJ_CFG_FULL_SWJ_NO_JNTRST;
}

/**
 * Set up USART2.
 * This one is connected via the virtual serial port on the Nucleo Board
 */
/*static void usart2_setup(uint32_t baud) {

  usart_disable(USART2);

  gpio_set_mode(GPIOA, GPIO_MODE_OUTPUT_50_MHZ, GPIO_CNF_OUTPUT_ALTFN_PUSHPULL,
                GPIO_USART2_TX | GPIO_USART2_RX);

  usart_set_baudrate(USART2, baud);
  usart_set_databits(USART2, 8);
  usart_set_stopbits(USART2, USART_STOPBITS_1);
  usart_set_parity(USART2, USART_PARITY_NONE);
  usart_set_flow_control(USART2, USART_FLOWCONTROL_NONE);
  usart_set_mode(USART2, USART_MODE_TX_RX);

  usart_enable(USART2);
}*/

void spi1_setup(void) {

  /* Configure GPIOs: SS=PA4, SCK=PA5, MISO=PA6 and MOSI=PA7 */
  gpio_set_mode(GPIOA, GPIO_MODE_OUTPUT_50_MHZ,
                GPIO_CNF_OUTPUT_ALTFN_PUSHPULL, GPIO4 |
                                                GPIO5 |
                                                GPIO7 );

  gpio_set_mode(GPIOA, GPIO_MODE_INPUT, GPIO_CNF_INPUT_FLOAT,
                GPIO6);

  /* Reset SPI, SPI_CR1 register cleared, SPI is disabled */
  spi_reset(SPI1);

  /* Set up SPI in Master mode with:
   * Clock baud rate: 1/64 of peripheral clock frequency
   * Clock polarity: Idle High
   * Clock phase: Data valid on 2nd clock pulse
   * Data frame format: 8-bit
   * Frame format: MSB First
   */
  spi_init_master(SPI1, SPI_CR1_BAUDRATE_FPCLK_DIV_64, SPI_CR1_CPOL_CLK_TO_1_WHEN_IDLE,
                  SPI_CR1_CPHA_CLK_TRANSITION_2, SPI_CR1_DFF_8BIT, SPI_CR1_MSBFIRST);

  /*
   * Set NSS management to software.
   *
   * Note:
   * Setting nss high is very important, even if we are controlling the GPIO
   * ourselves this bit needs to be at least set to 1, otherwise the spi
   * peripheral will not send any data out.
   */
  spi_enable_software_slave_management(SPI1);
  spi_set_nss_high(SPI1);

  /* Enable SPI1 periph. */
  spi_enable(SPI1);
}

/**
 * initialise and start SysTick counter. This will trigger the
 * sys_tick_handler() periodically once interrupts have been enabled
 * by archFirstThreadRestore()
 */
void systick_setup(void) {
  systick_set_frequency(SYSTEM_TICKS_PER_SEC, 72000000);
  systick_interrupt_enable();
  systick_counter_enable();
}

void gpio_setup(void) {
  // USB pins
  gpio_set_mode(GPIOA, GPIO_MODE_OUTPUT_2_MHZ, GPIO_CNF_OUTPUT_ALTFN_OPENDRAIN, GPIO9 | GPIO10 | GPIO11 | GPIO12 );
  gpio_set_mode(USB_PULLUP_PORT, GPIO_MODE_OUTPUT_50_MHZ,
              GPIO_CNF_OUTPUT_PUSHPULL, USB_PULLUP_GPIO);
}
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

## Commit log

2017-06-28 first run on stm32f107vc is wrong. It seems that linked script should be improved
    [board_setup.c, main.c]
2018-05-09 EAGLE files copied into the project folder
    [Crimea (SilverStone's conflicted copy 2017-06-02).brd, Crimea (SilverStone's conflicted copy 2017-06-02).sch, Crimea.brd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]

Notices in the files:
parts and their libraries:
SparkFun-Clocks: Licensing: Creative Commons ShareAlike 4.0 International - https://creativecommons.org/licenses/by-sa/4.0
